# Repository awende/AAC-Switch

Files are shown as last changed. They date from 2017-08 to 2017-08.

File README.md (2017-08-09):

# AAC Switches

AAC Switch

For more information, check out the blog post for the project [here](https://www.sparkfun.com/news/2452).

Repository Contents
-------------------

* **/Proximity Switch** - All Eagle design files (.sch, .brd, .png)
* **/Bluetooth Bridge** - Schematic and Arduino Code (.png, .ino)

License Information
-------------------
The hardware is released under [Creative Commons ShareAlike 4.0 International](https://creativecommons.org/licenses/by-sa/4.0/).
The code is beerware; if you see me at the local, and you've found our designs helpful, please buy us a round!

Distributed as-is; no warranty is given.

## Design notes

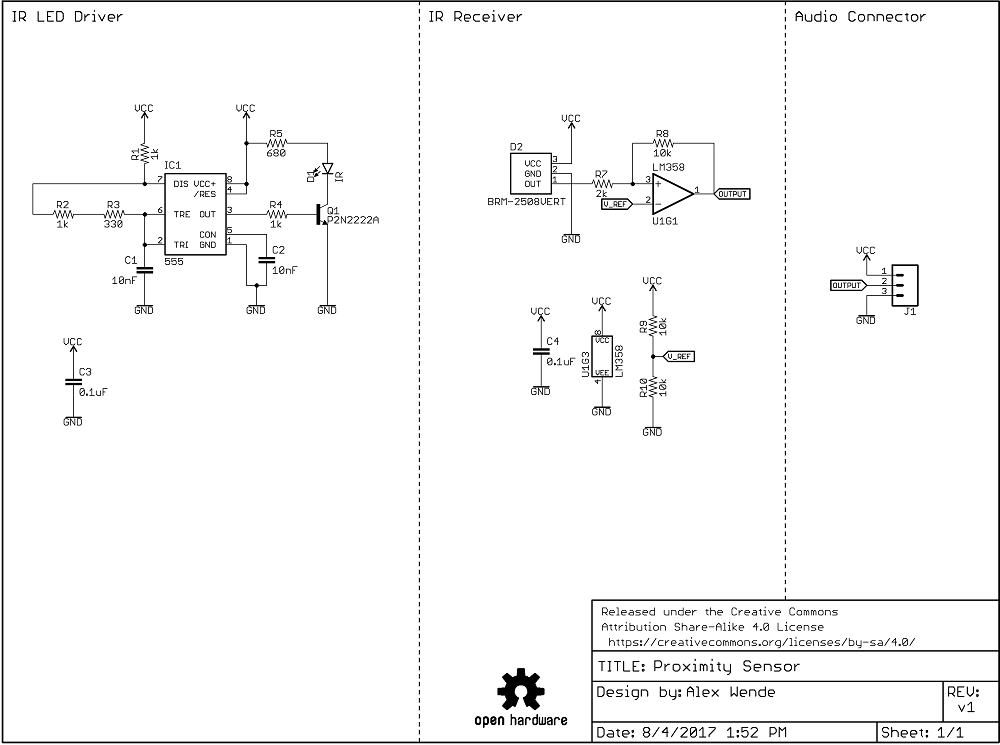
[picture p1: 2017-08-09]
Proximity Switch/Proximity Sensor Schematic.png

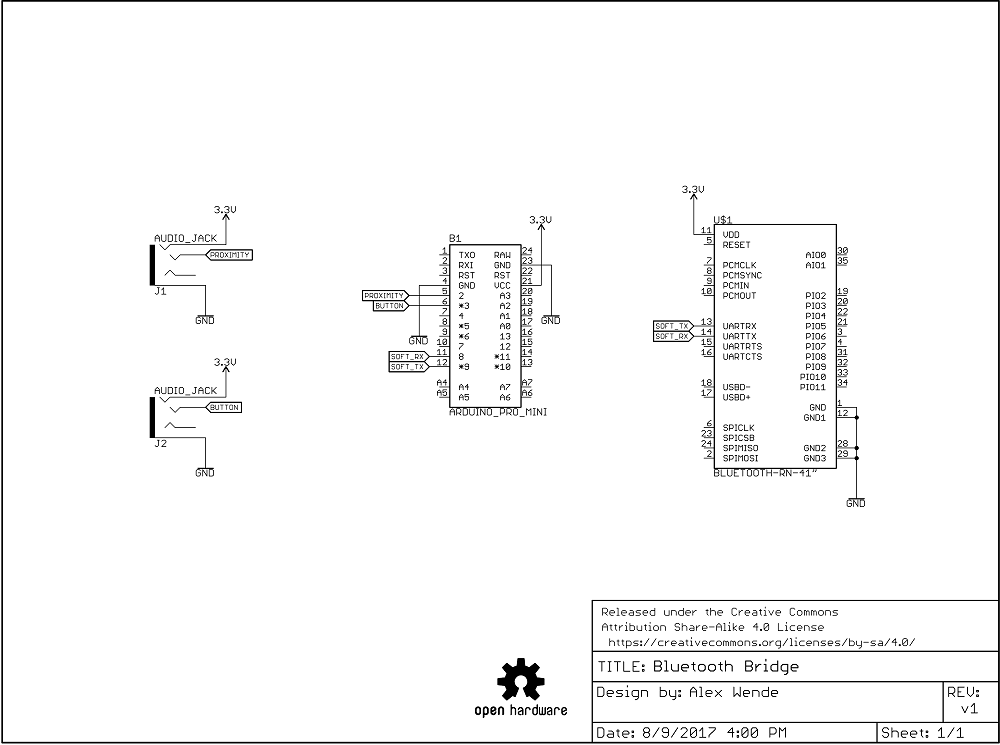
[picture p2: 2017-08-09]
Bluetooth Bridge/Bluetooth Bridge Schematic.png

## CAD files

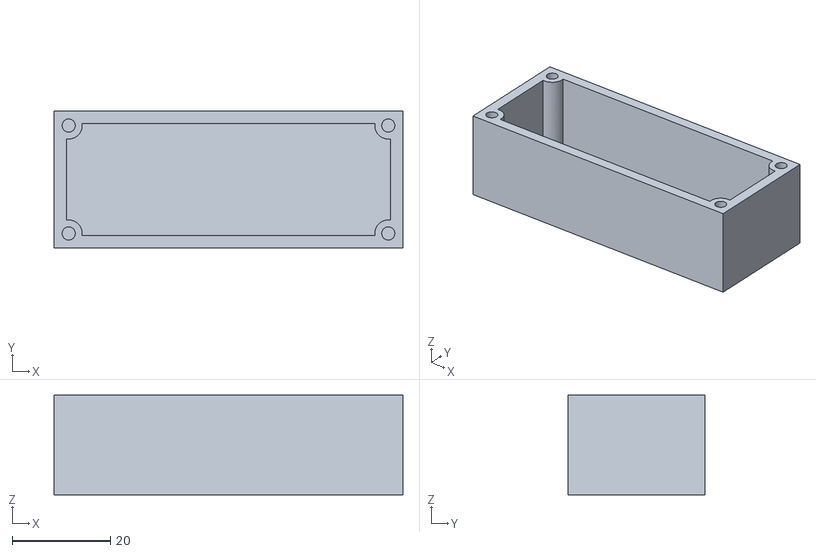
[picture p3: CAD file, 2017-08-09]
Proximity Switch/Proximity Switch Case.stl
71.1 x 28.0 x 20.3

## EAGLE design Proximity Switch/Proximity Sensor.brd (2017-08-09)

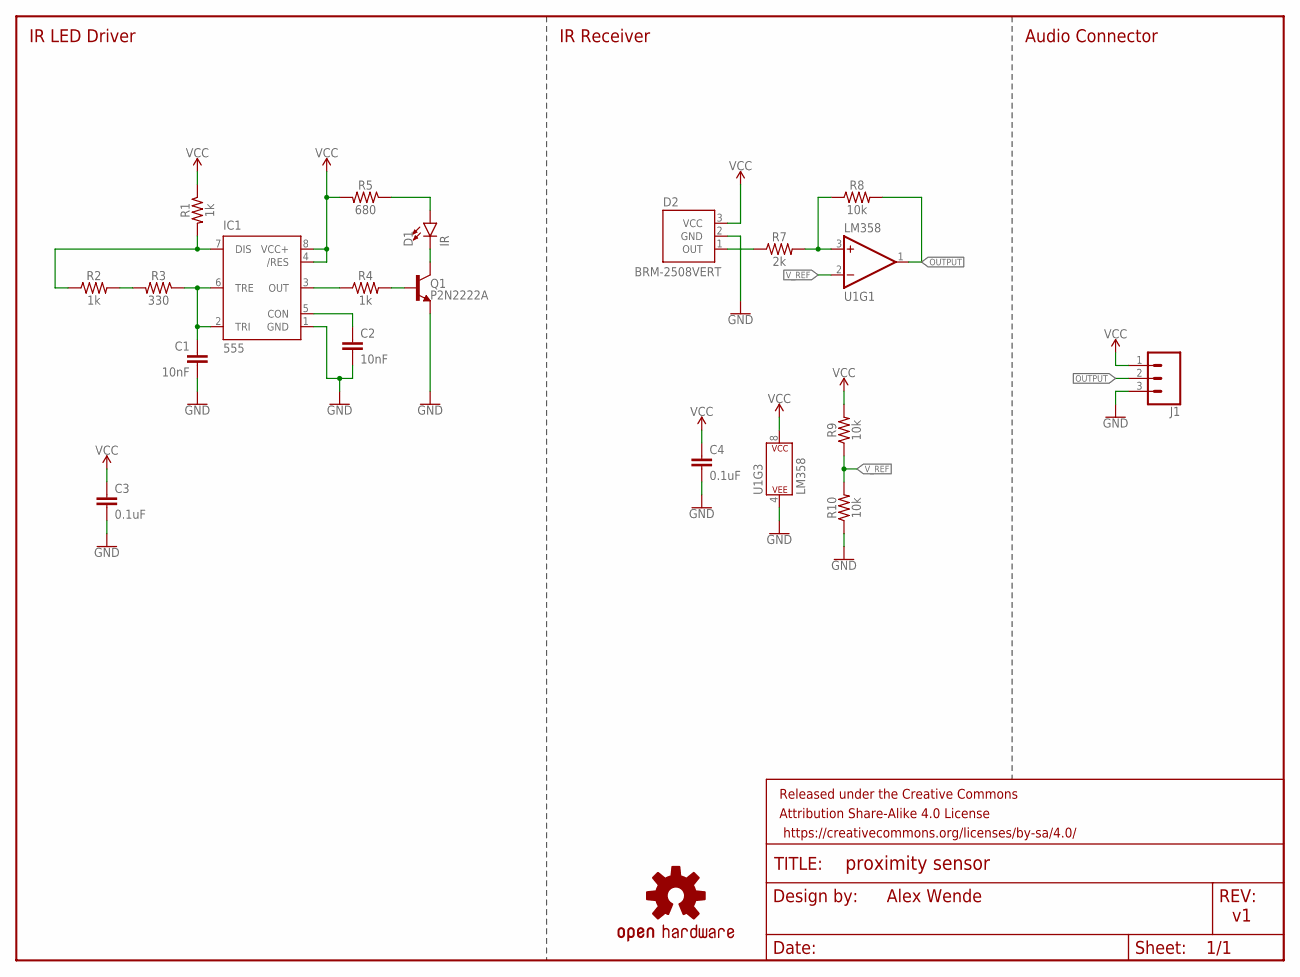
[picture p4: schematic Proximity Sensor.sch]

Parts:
C1, C2: 10nF; CAP-PTH-10MM
C3, C4: 0.1uF; CAP-PTH-SMALL-KIT
D1: IR; LED_5MM-KIT
D2: BRM-2508VERT; BRM-2508_VERT
FRAME1: FRAME-LETTERNO_PACKAGE; DUMMY
IC1: 555; DIP08-KIT
J1: CONN_03LONGPADS; 1X03_LONGPADS
LOGO1: OSHW-LOGOM; OSHW-LOGO-M
Q1: P2N2222A; TO-92
R1, R2, R4: 1k; AXIAL-0.3-KIT
R3: 330; AXIAL-0.3-KIT
R5: 680; AXIAL-0.3-KIT
R7: 2k; AXIAL-0.3-KIT
R8, R9, R10: 10k; AXIAL-0.3-KIT
U1: LM358; DIP08-KIT

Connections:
GND: C1.2, C2.2, C3.2, C4.2, D2.2 (GND), IC1.1 (GND), J1.3, Q1.3 (E), R10.P$1 (1), U1.4 (P$V-)
unnamed: C1.1, IC1.2 (TRI), IC1.6 (TRE), R3.P$1 (1)
unnamed: IC1.7 (DIS), R1.P$2 (2), R2.P$1 (1)
unnamed: C2.1, IC1.5 (CON)
unnamed: R2.P$2 (2), R3.P$2 (2)
unnamed: Q1.2 (B), R4.P$2 (2)
unnamed: IC1.3 (OUT), R4.P$1 (1)
unnamed: D1.A, R5.P$1 (1)
unnamed: D1.K (C), Q1.1 (C)
unnamed: R7.P$2 (2), R8.P$1 (1), U1.3 (+IN)
unnamed: D2.1 (OUT), R7.P$1 (1)
OUTPUT: J1.2, R8.P$2 (2), U1.1 (OUT)
VCC: C3.1, C4.1, D2.3 (VCC), IC1.4 (/RES), IC1.8 (VCC+), J1.1, R1.P$1 (1), R5.P$2 (2), R9.P$2 (2), U1.8 (P$V+)
V_REF: R9.P$1 (1), R10.P$2 (2), U1.2 (-IN)

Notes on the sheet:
Alex Wende
IR LED Driver
IR Receiver
Audio Connector

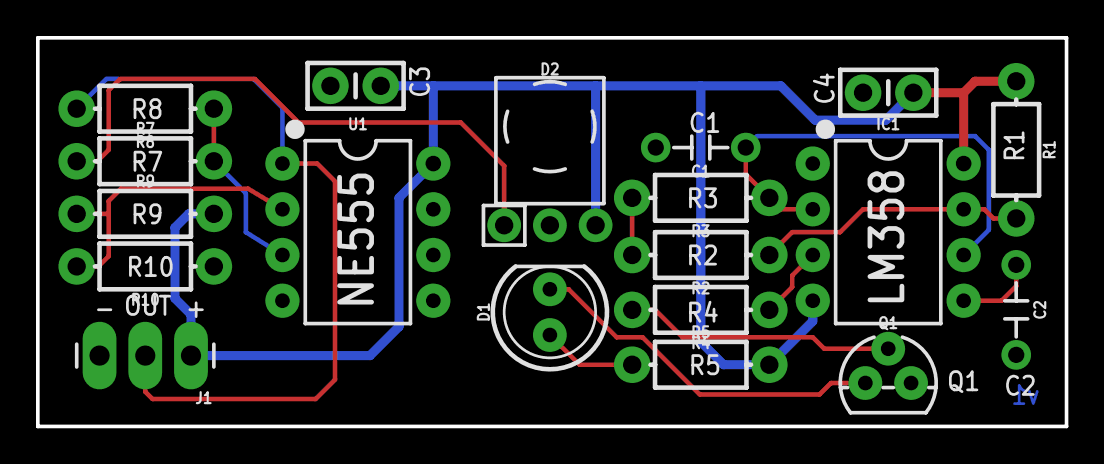
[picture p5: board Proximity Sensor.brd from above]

Board: 2 copper layers, 57.1 x 21.6 mm, 21 parts (1 on the bottom side), 14 nets.

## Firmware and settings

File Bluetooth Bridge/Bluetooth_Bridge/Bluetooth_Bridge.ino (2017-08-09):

#include<SoftwareSerial.h>

SoftwareSerial soft(8,9); // Used to communicate with the RN-41. 8-RX, 9-TX

const byte button=3, proximity=2; // Pins used to sense if button has been pressed

void setup() {
  Serial.begin(115200); // Used for debugging
  soft.begin(115200);   // used for communicating with the RN-41
  
  pinMode(2,INPUT_PULLUP);
  pinMode(3,INPUT_PULLUP);
}

void loop() {
  if(digitalRead(button) == 0)  // Button switch is pressed
  {
    soft.print(char(5));
    Serial.println("Button Pressed");
    while(digitalRead(button) == 0) // Wait for button to be released
    {
      delay(5);
    }
  }
  if(digitalRead(proximity) == 0) // Proximity switch is "pressed"
  {
    soft.print(char(6));
    Serial.println("Proximity Pressed");
    while(digitalRead(proximity) != 0)  // Wait for button to be released
    {
      delay(5);
    }
  }
}

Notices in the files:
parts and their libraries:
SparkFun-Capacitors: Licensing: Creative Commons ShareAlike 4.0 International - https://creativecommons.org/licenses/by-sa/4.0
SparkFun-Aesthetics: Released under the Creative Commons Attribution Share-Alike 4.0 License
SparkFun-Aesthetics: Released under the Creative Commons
